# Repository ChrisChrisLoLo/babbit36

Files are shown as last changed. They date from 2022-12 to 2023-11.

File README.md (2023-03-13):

# babbit36

image of babbit36

A 36 key low profile wireless ortholinear board. Uses a Seediuno XIAO as the MCU, and runs on ZMK.
Featues:
  - Low Profile, uses CFX keycaps
  - Commodity parts, only non standard part is the shift register
  - Relatively affordable! 
    - Case only requires one CNC/3D Printed part and one FR4 backplate

## Note
This keyboard uses CFX spacing, and therefore requires Chosfox CFX keycaps, or keycaps with similar spacing.

## Status
v0 is functional and works as is!  

## PCB/CNC case

You can generate the gerbers from source in the pcb directory, and send off imediately to PCBWay or the like. There's one gerber for the keyboard and another gerber for the backplate of the case. There's also step files ready to use to order your own 3DP/CNC case. My CNC case was sponsored by PCBWay. I was a bit anxious about my CNC file since this is my most complicated keyboard case to date, but PCBWay did a fantastic job! I was very happy that the tolerances were good, that the finishing looked great, and that it was all at a great price given the complexity of the case! I highly recommend their services for CNC prototyping/manufacturing!

## BOM
The following is the materials you will want/need to make your own babbit36. Note that anything amount after a + denotes the rough amount of spares you may want to have when ordering the parts.
| Part | Count | Notes |
|---|---|---|
| PCB | 1 |  |
|Kailh Choc Hotswap Switches |36+4|| 	
|LL4148 SMD Diodes |	36+4 |	This board uses SMD diodes exclusively. I found though-hole diodes often easily slipped around in a way such that the board was no longer able to fit inside the case|
|Seeduino XIAO nrf52|1||
|74hc595 SMD|1|SMD Shift Register|
|SMD power switch|1||
|Lipo battery|1|A 3.7V 110mAh 301230 will fit nicely in the case|
|Rubber Feet 	|6+2| 	Any should generally work, though I'm using ~2.5mm thick ones, as they give more space for screw heads, as well as the magnetic connector I'm using|
|CNC Printed Case 	|1 	|You could use PCB printing services like PCBWay to make one in resin, though I haven't confirmed if they'd be durable enough to survive in transit|
|PCB/FR4 backplate | 1| For the back of the keyboard case. Can be found in the pcb folder |
|M2 4mm Screw |	6+2 |	Screws for the PCB and case. Be careful of the size of the screw head! the flatter the better!

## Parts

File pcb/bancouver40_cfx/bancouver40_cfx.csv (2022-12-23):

Id | Designator | Package | Quantity | Designation | Supplier and ref
1 | SW25,SW17,SW23,SW26,SW13,SW20,SW16,SW4,SW1,SW29,SW15,SW34,SW6,SW10,SW33,SW27,SW30,SW7,SW19,SW40,SW24,SW32,SW5,SW31,SW38,SW35,SW18,SW3,SW9,SW14,SW21,SW2,SW12,SW36,SW22,SW28,SW37,SW11,SW39,SW8 | Kailh_socket_PG1350 | 40 | SW_Push
2 | H4,H5,H2,H6,H3,H1 | MountingHole_2.2mm_M2_ISO7380 | 6 | MountingHole
3 | D35,D31,D30,D34,D11,D8,D22,D24,D27,D4,D40,D29,D28,D33,D15,D9,D21,D32,D19,D10,D14,D6,D18,D16,D13,D25,D26,D1,D3,D7,D23,D17,D12,D5,D37,D36,D39,D20,D38,D2 | D_SOD-323 | 40 | D_Small
4 | C5,C4,C6 | C_0402_1005Metric | 3 | 0.1uF
5 | R4,R5 | R_0402_1005Metric | 2 | 22
6 | U1 | QFN-44-1EP_7x7mm_P0.5mm_EP5.2x5.2mm | 1 | ATmega32U4-M
7 | C2,C1 | C_0402_1005Metric | 2 | 22pF
8 | Y1 | Crystal_SMD_3225-4Pin_3.2x2.5mm | 1 | 16MHz
9 | C7 | C_0402_1005Metric | 1 | 10uF
10 | R6,R1 | R_0402_1005Metric | 2 | 10k
11 | B1 | SW_SPST_SKQG_WithoutStem | 1 | SW_Push
12 | R3,R2 | R_0402_1005Metric | 2 | 5k1
13 | J1 | USB_C_Receptacle_XKB_U262-16XN-4BVC11 | 1 | USB_C_Receptacle_USB2.0
14 | F1 | Fuse_1206_3216Metric | 1 | 500mA
15 | C3 | C_0402_1005Metric | 1 | 1uF

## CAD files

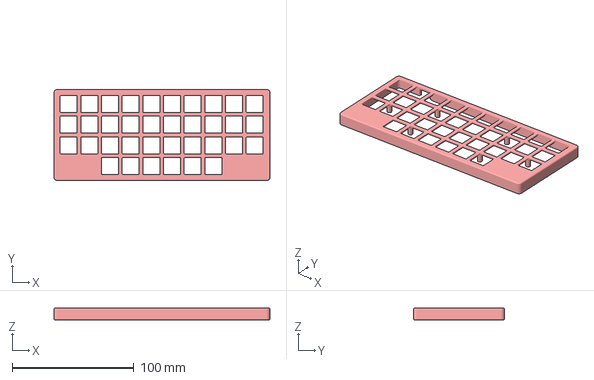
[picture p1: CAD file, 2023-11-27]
case/cnc2/babbit36_low_pro.3mf
177.7 x 75.2 x 9.80 mm

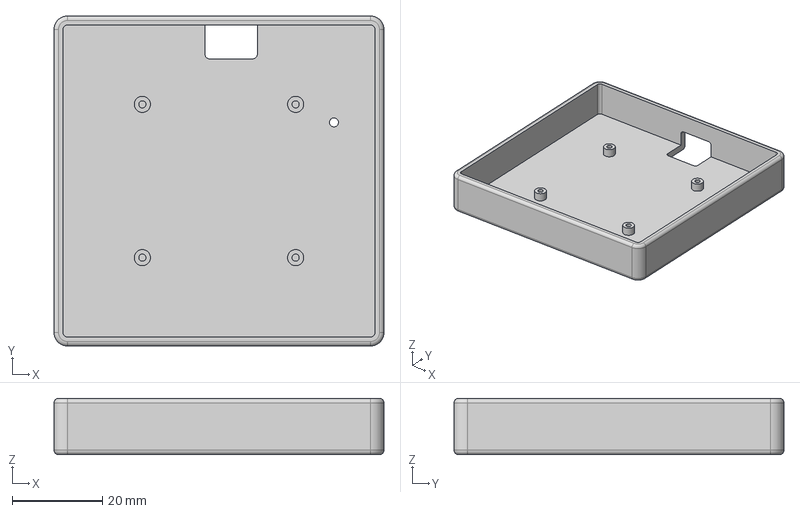
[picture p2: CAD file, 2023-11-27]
case/cnc2/kowgary_manu/kowgary16 cnc final v3.step
73.2 x 73.2 x 12.5 mm

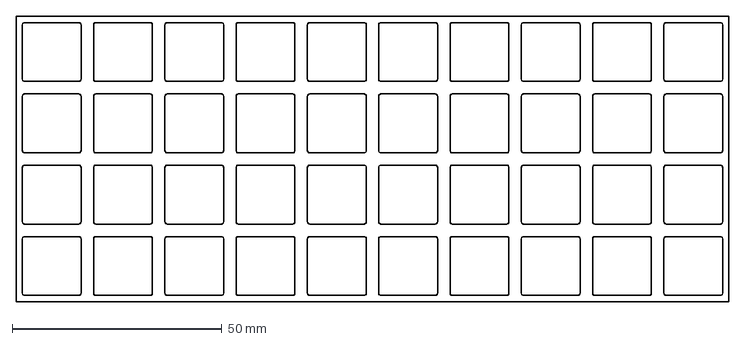
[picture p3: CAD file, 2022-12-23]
outlines/cfx_spacing/plate-2022-10-10T04 27 35.834Z.dxf
170.0 x 68.0 mm

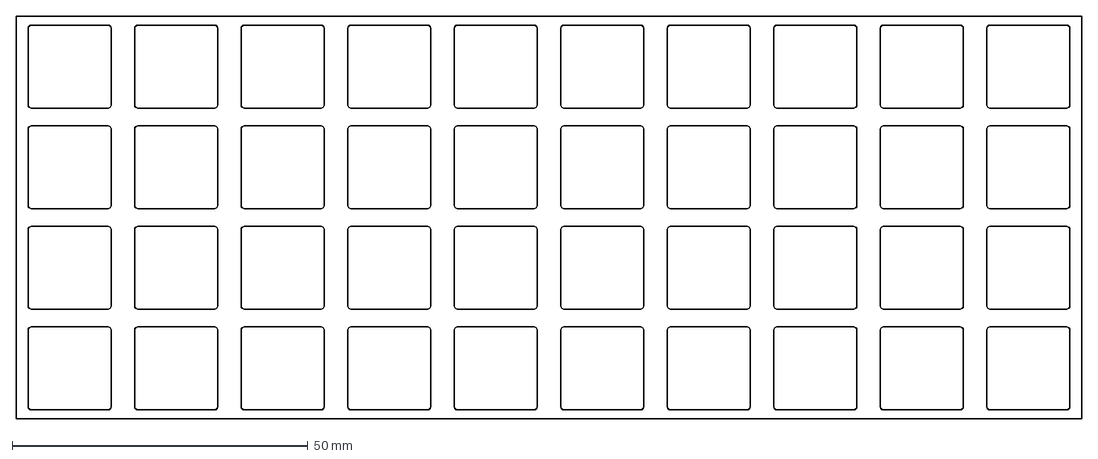
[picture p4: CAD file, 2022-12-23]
outlines/choc_spacing/plate-2022-10-10T15 28 30.631Z.dxf
180.0 x 68.0 mm

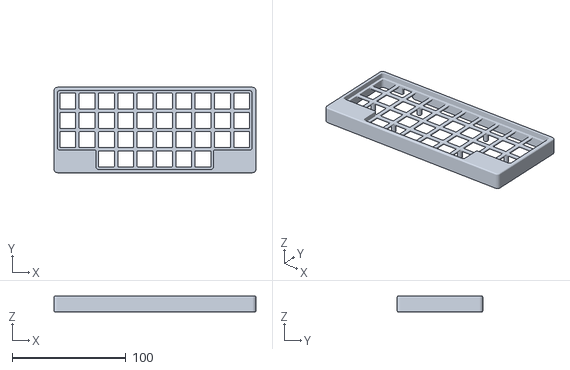
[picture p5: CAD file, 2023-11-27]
case/cnc2/babbit36 v35.stl
177.7 x 75.2 x 14.0

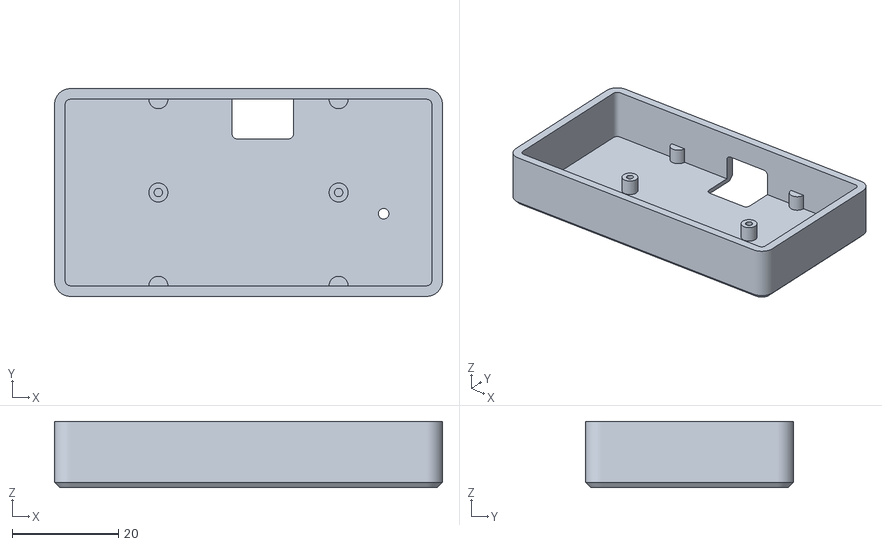
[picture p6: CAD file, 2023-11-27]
case/cnc2/kibbi8_3DP_Case.stl
73.2 x 39.2 x 12.5

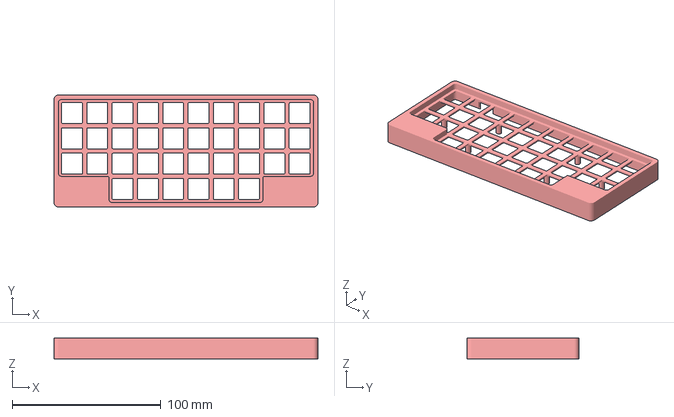
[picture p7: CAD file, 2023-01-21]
case/cnc2/Body1.3mf
177.4 x 75.2 x 14.0 mm

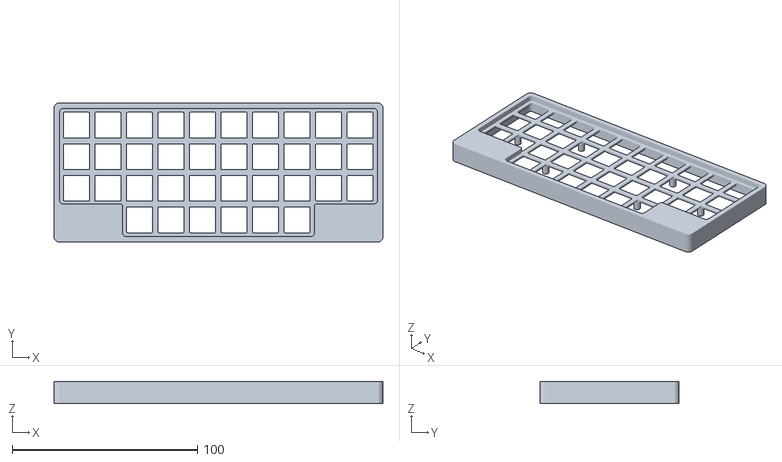
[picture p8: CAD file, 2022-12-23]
case/cnc2/integrated_plate_2.stl
177.4 x 75.2 x 12.0

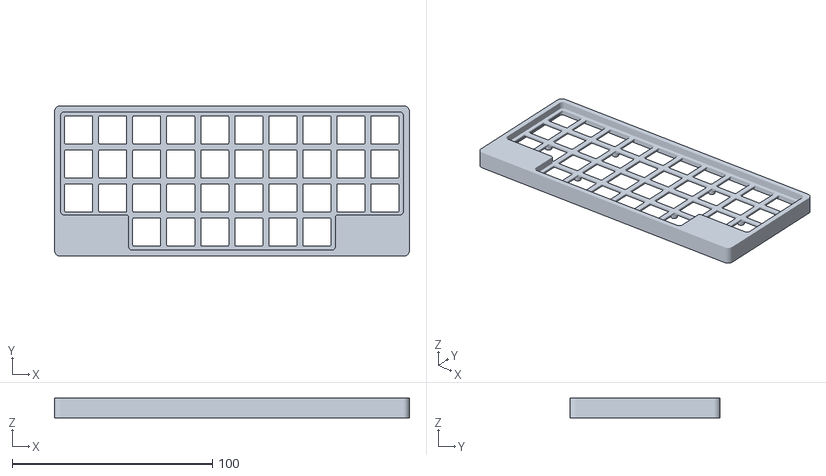
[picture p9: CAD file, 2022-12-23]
case/cnc2/integrated_plate.stl
177.4 x 75.2 x 9.80

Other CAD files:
case/cnc2/babbit_manu/Babbit36-lo-pro v6.step
case/cnc2/bancouver40_3DP_Case.stl
case/cnc2/Babbit36-lo-pro v6.step
case/cnc2/babbit36 v22.stl
case/cnc2/Babbit36-lo-pro v2.step
case/cnc2/Babbit36-lo-pro v2.stl
case/cnc2/Body1.stl
case/cnc2/babbit36_low_pro.stl

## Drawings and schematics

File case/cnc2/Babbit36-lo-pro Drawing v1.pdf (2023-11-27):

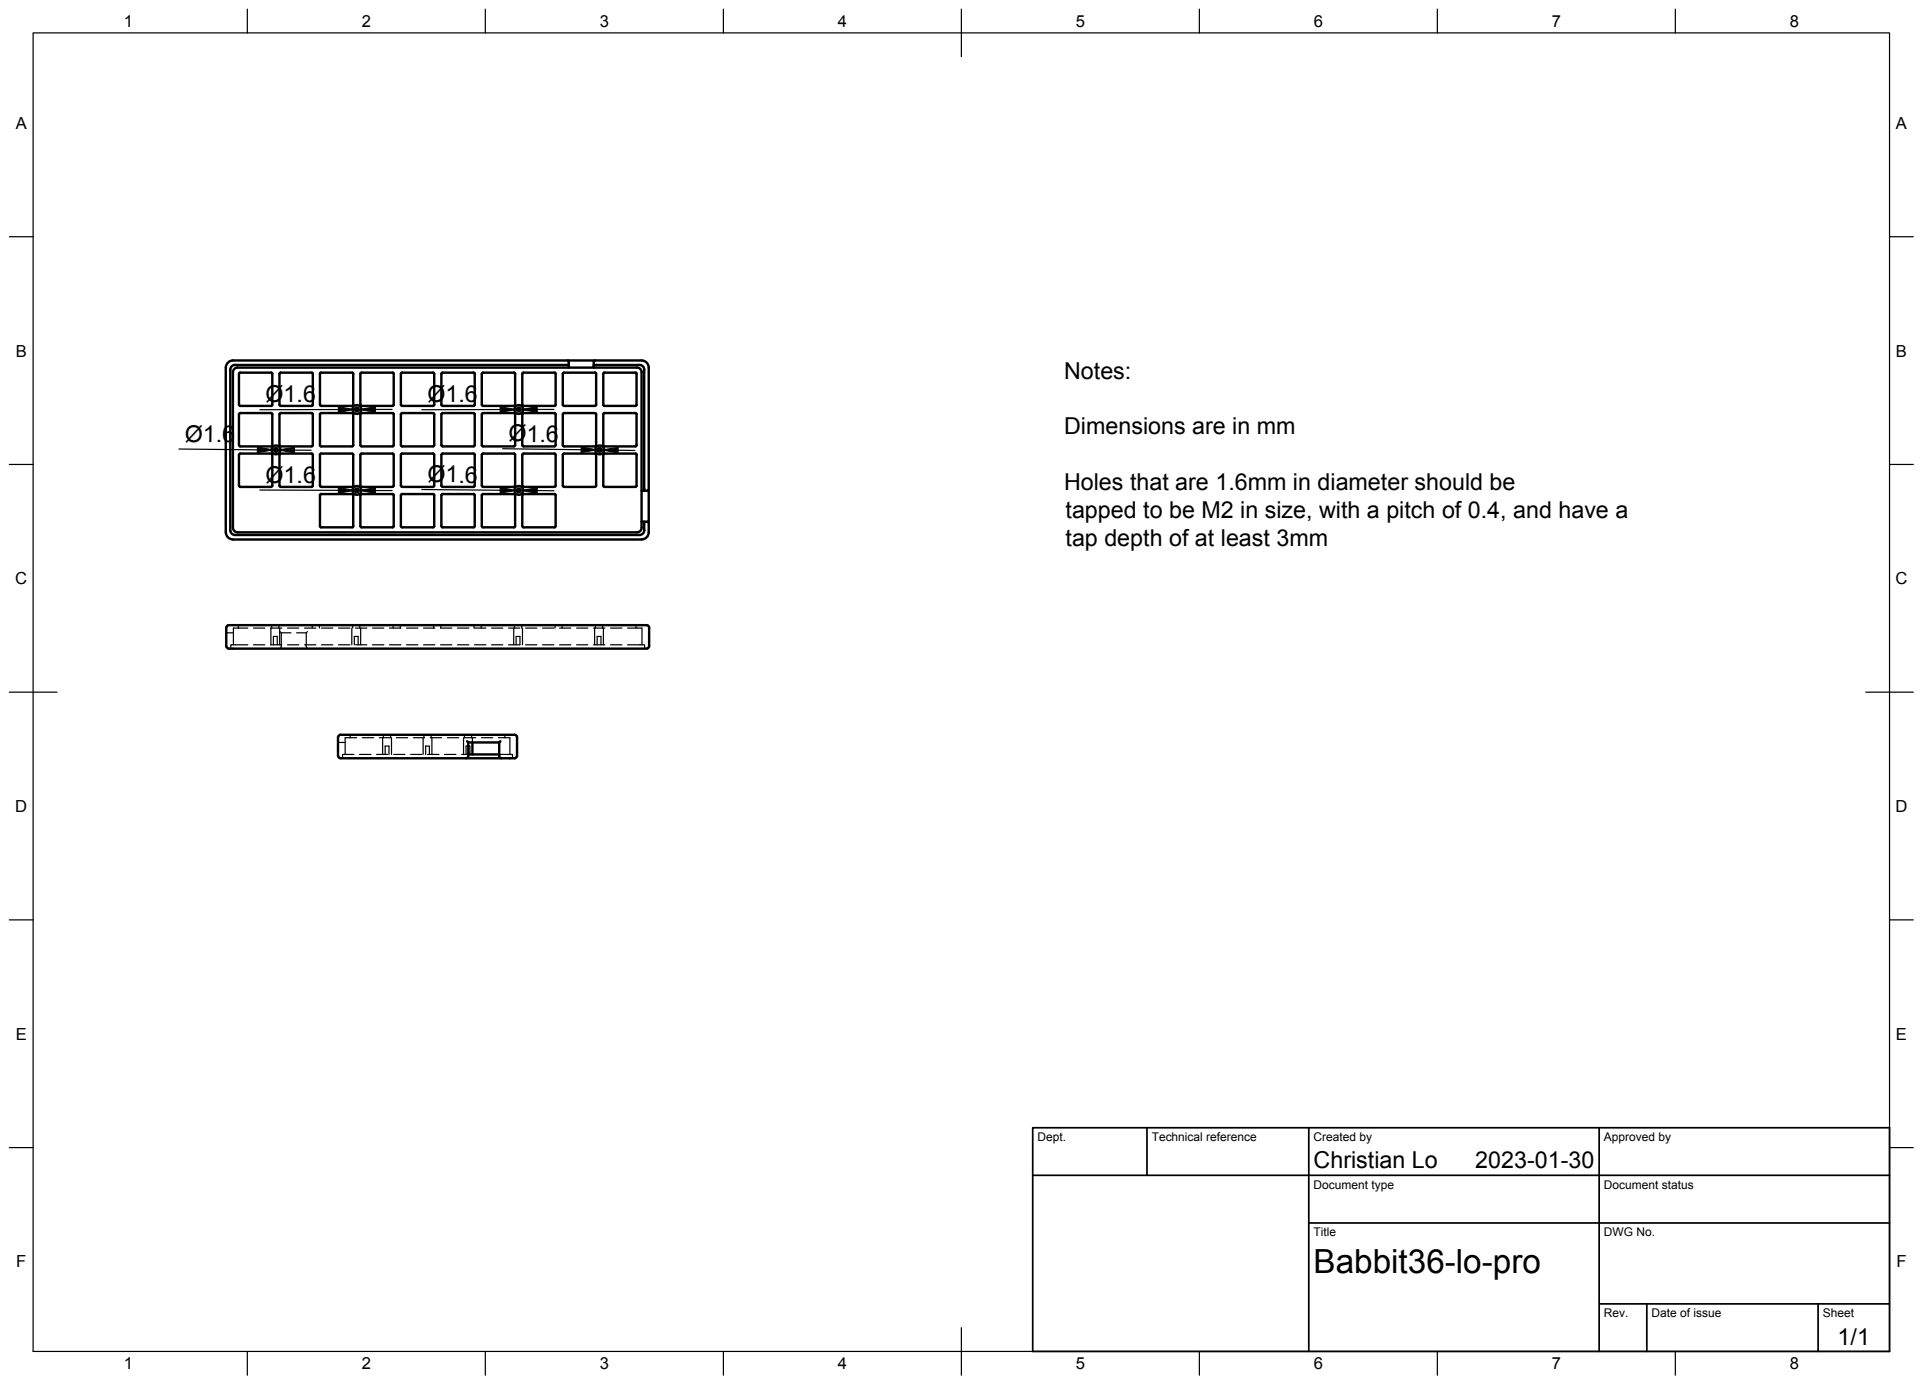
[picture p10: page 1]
Title; DWG No.; Rev.; Date of issue; Sheet

Dimensions are in mm

Holes that are 1.6mm in diameter should be
tapped to be M2 in size, with a pitch of 0.4, and have a
tap depth of at least 3mm

Dept. | Technical reference | Created by Christian Lo 2023-01-30 | Approved by

Document type | Document status

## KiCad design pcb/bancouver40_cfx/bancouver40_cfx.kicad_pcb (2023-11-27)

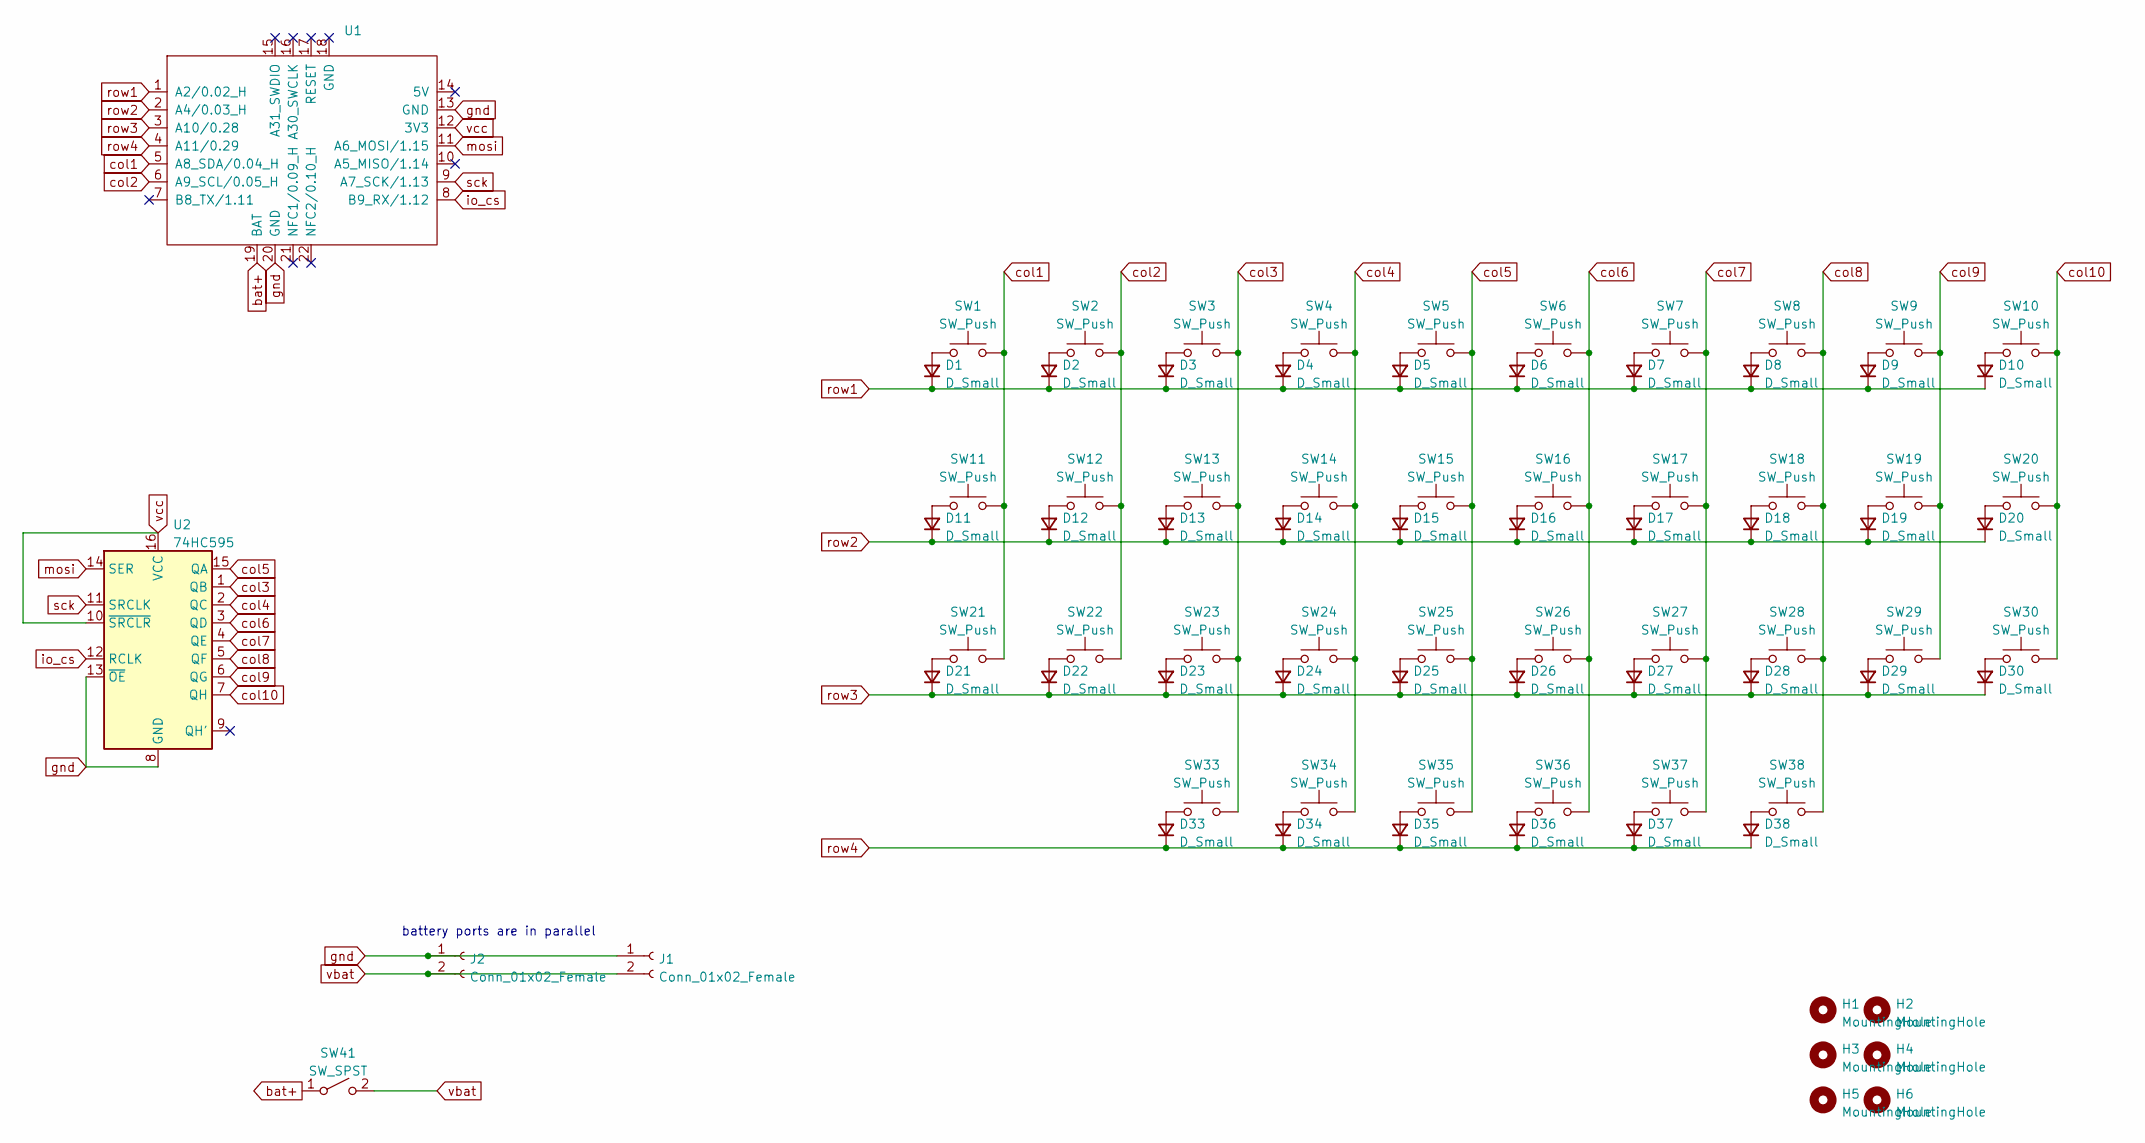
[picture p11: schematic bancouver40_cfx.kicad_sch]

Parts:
D1, D2, D3, D4, D5, D6, D7, D8, D9, D10, D11, D12, D13, D14, D15, D16, D17, D18, D19, D20, D21, D22, D23, D24, D25, D26, D27, D28, D29, D30, D33, D34, D35, D36, D37, D38: D_Small
H1, H2, H3, H4, H5, H6: MountingHole
J1: Conn_01x02_Female; JST_PH_S2B-PH-K_1x02_P2.00mm_Horizontal
J2: Conn_01x02_Female; PinHeader_1x02_P2.54mm_Vertical
SW1, SW2, SW3, SW4, SW5, SW6, SW7, SW8, SW9, SW10, SW11, SW12, SW13, SW14, SW15, SW16, SW17, SW18, SW19, SW20, SW21, SW22, SW23, SW24, SW25, SW26, SW27, SW28, SW29, SW30, SW33, SW34, SW35, SW36, SW37, SW38: SW_Push; Kailh_socket_PG1350
SW41: SW_SPST; SW_SPDT_PCM12
U1: (no value)
U2: 74HC595; SOIC-16_3.9x9.9mm_P1.27mm

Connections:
unnamed: D1.2 (A), SW1.1
unnamed: D2.2 (A), SW2.1
unnamed: D3.2 (A), SW3.1
unnamed: D4.2 (A), SW4.1
unnamed: D5.2 (A), SW5.1
unnamed: D6.2 (A), SW6.1
unnamed: D7.2 (A), SW7.1
unnamed: D8.2 (A), SW8.1
unnamed: D9.2 (A), SW9.1
unnamed: D10.2 (A), SW10.1
unnamed: D11.2 (A), SW11.1
unnamed: D12.2 (A), SW12.1
unnamed: D13.2 (A), SW13.1
unnamed: D14.2 (A), SW14.1
unnamed: D15.2 (A), SW15.1
unnamed: D16.2 (A), SW16.1
unnamed: D17.2 (A), SW17.1
unnamed: D18.2 (A), SW18.1
unnamed: D19.2 (A), SW19.1
unnamed: D20.2 (A), SW20.1
unnamed: D21.2 (A), SW21.1
unnamed: D22.2 (A), SW22.1
unnamed: D23.2 (A), SW23.1
unnamed: D24.2 (A), SW24.1
unnamed: D25.2 (A), SW25.1
unnamed: D26.2 (A), SW26.1
unnamed: D27.2 (A), SW27.1
unnamed: D28.2 (A), SW28.1
unnamed: D29.2 (A), SW29.1
unnamed: D30.2 (A), SW30.1
unnamed: D33.2 (A), SW33.1
unnamed: D34.2 (A), SW34.1
unnamed: D35.2 (A), SW35.1
unnamed: D36.2 (A), SW36.1
unnamed: D37.2 (A), SW37.1
unnamed: D38.2 (A), SW38.1
bat+: SW41.1 (A), U1.19 (BAT)
col1: SW1.2, SW11.2, SW21.2, U1.5 (A8_SDA/0.04_H)
col2: SW2.2, SW12.2, SW22.2, U1.6 (A9_SCL/0.05_H)
col3: SW3.2, SW13.2, SW23.2, SW33.2, U2.1 (QB)
col4: SW4.2, SW14.2, SW24.2, SW34.2, U2.2 (QC)
col5: SW5.2, SW15.2, SW25.2, SW35.2, U2.15 (QA)
col6: SW6.2, SW16.2, SW26.2, SW36.2, U2.3 (QD)
col7: SW7.2, SW17.2, SW27.2, SW37.2, U2.4 (QE)
col8: SW8.2, SW18.2, SW28.2, SW38.2, U2.5 (QF)
col9: SW9.2, SW19.2, SW29.2, U2.6 (QG)
col10: SW10.2, SW20.2, SW30.2, U2.7 (QH)
gnd: J1.1, J2.1, U1.13 (GND), U1.20 (GND), U2.8 (GND), U2.13 (~OE)
io_cs: U1.8 (B9_RX/1.12), U2.12 (RCLK)
mosi: U1.11 (A6_MOSI/1.15), U2.14 (SER)
reset: U1.17 (RESET)
row1: D1.1 (K), D2.1 (K), D3.1 (K), D4.1 (K), D5.1 (K), D6.1 (K), D7.1 (K), D8.1 (K), D9.1 (K), D10.1 (K), U1.1 (A2/0.02_H)
row2: D11.1 (K), D12.1 (K), D13.1 (K), D14.1 (K), D15.1 (K), D16.1 (K), D17.1 (K), D18.1 (K), D19.1 (K), D20.1 (K), U1.2 (A4/0.03_H)
row3: D21.1 (K), D22.1 (K), D23.1 (K), D24.1 (K), D25.1 (K), D26.1 (K), D27.1 (K), D28.1 (K), D29.1 (K), D30.1 (K), U1.3 (A10/0.28)
row4: D33.1 (K), D34.1 (K), D35.1 (K), D36.1 (K), D37.1 (K), D38.1 (K), U1.4 (A11/0.29)
sck: U1.9 (A7_SCK/1.13), U2.11 (SRCLK)
vbat: J1.2, J2.2, SW41.2 (B)
vcc: U1.12 (3V3), U2.10 (~SRCLR), U2.16 (VCC)

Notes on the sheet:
battery ports are in parallel

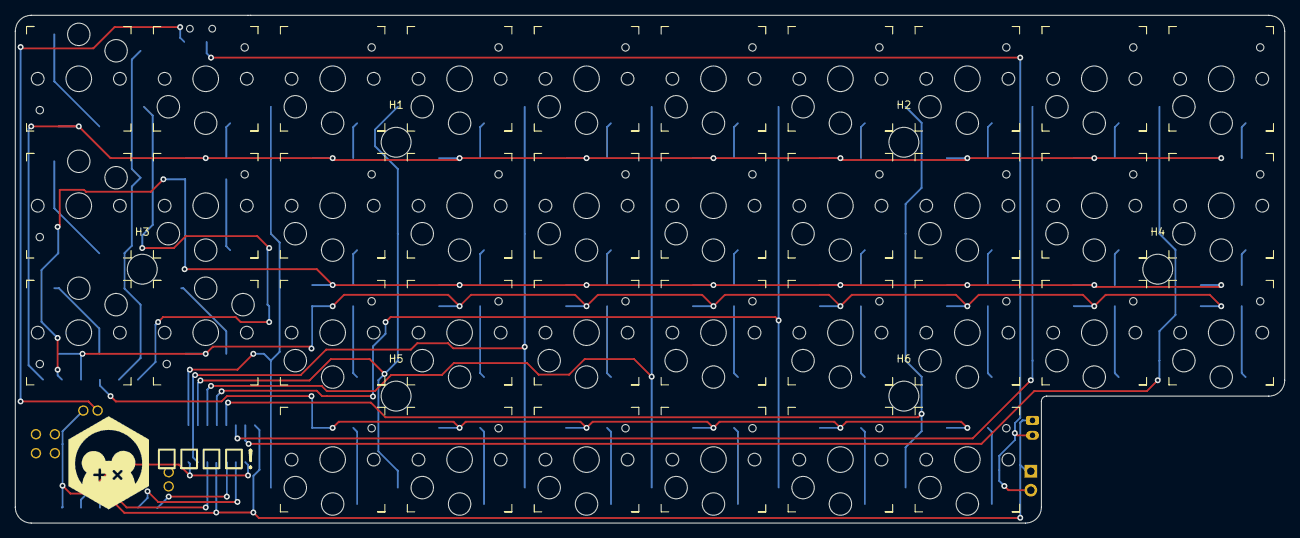
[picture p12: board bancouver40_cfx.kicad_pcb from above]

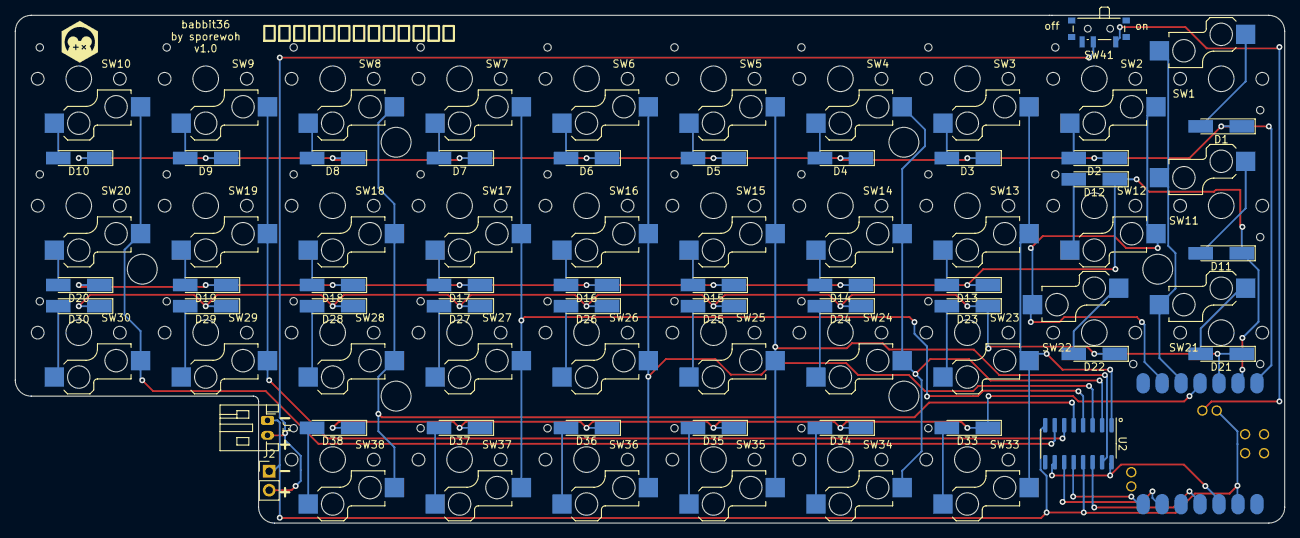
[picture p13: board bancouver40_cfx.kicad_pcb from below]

Board: 2 copper layers, 170.0 x 68.0 mm, 83 parts (41 on the bottom side), 57 nets.

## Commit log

2023-01-21 add case
    [Body1.3mf, Body1.stl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]
2023-11-27 add cnc files
    [Babbit36-lo-pro v2.step, Babbit36-lo-pro v2.stl, Babbit36-lo-pro v6.step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]
